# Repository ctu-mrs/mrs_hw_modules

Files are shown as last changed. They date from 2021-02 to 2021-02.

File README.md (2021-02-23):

# MRS Modules
Modules for MRS drone distribution boards to add a specific funtionality the distribution boards do not provide.

These modules are equipped with 1x10 header with 2mm pitch providing the module with UART connection, 5V from USB and VBAT from battery.

## MRS Module Host
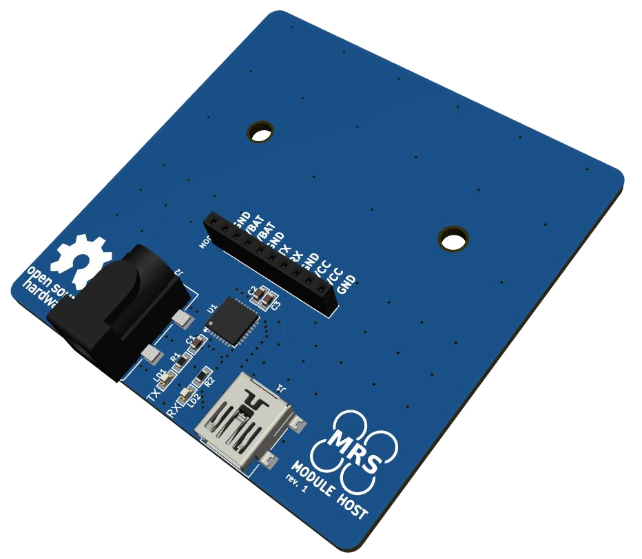
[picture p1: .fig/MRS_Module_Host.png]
mrs_module_host

This PCB serves as a host for MRS Modules for development. It's functionality is simple: provide power for VBAT pins (can be supplied using the 5.5/2.5mm barrel connector), power for the module's MCU and serial communication between the user's computer and the module's MCU (usinng the USB2.0B mini connector).

The VBAT input of the module is designed to be either 4S or 6S LiPo battery, but can be anything the designed module is capable of. Check the module's VBAT capabilities before plugging in any power source in case it is unsuitable and could damage the module.

## MRS Module Templates
Three templates are provided in case you aim to implement your own module: Small, Medium and Large.

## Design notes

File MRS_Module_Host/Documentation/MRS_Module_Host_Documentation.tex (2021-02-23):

\documentclass[12pt, a4paper]{article}

\usepackage[export]{adjustbox}
\usepackage{fancyhdr}
\usepackage[utf8]{inputenc}
\usepackage[english]{babel}
\usepackage{longtable}
\usepackage[margin=2cm, bottom=4cm]{geometry}
\usepackage{color,soul}
\usepackage{booktabs}
\usepackage{pdfpages}

\pagestyle{fancy}
\fancyhf{}% Clear all headers/footers
\renewcommand{\headrulewidth}{.4pt}% Header rule width
\renewcommand{\footrulewidth}{0pt}% No footer rule
\fancyhead[L]{% Left header
  \rule[-1\baselineskip]{0pt}{0pt}% Strut to ensure a 1/4 \baselineskip between image and header rule
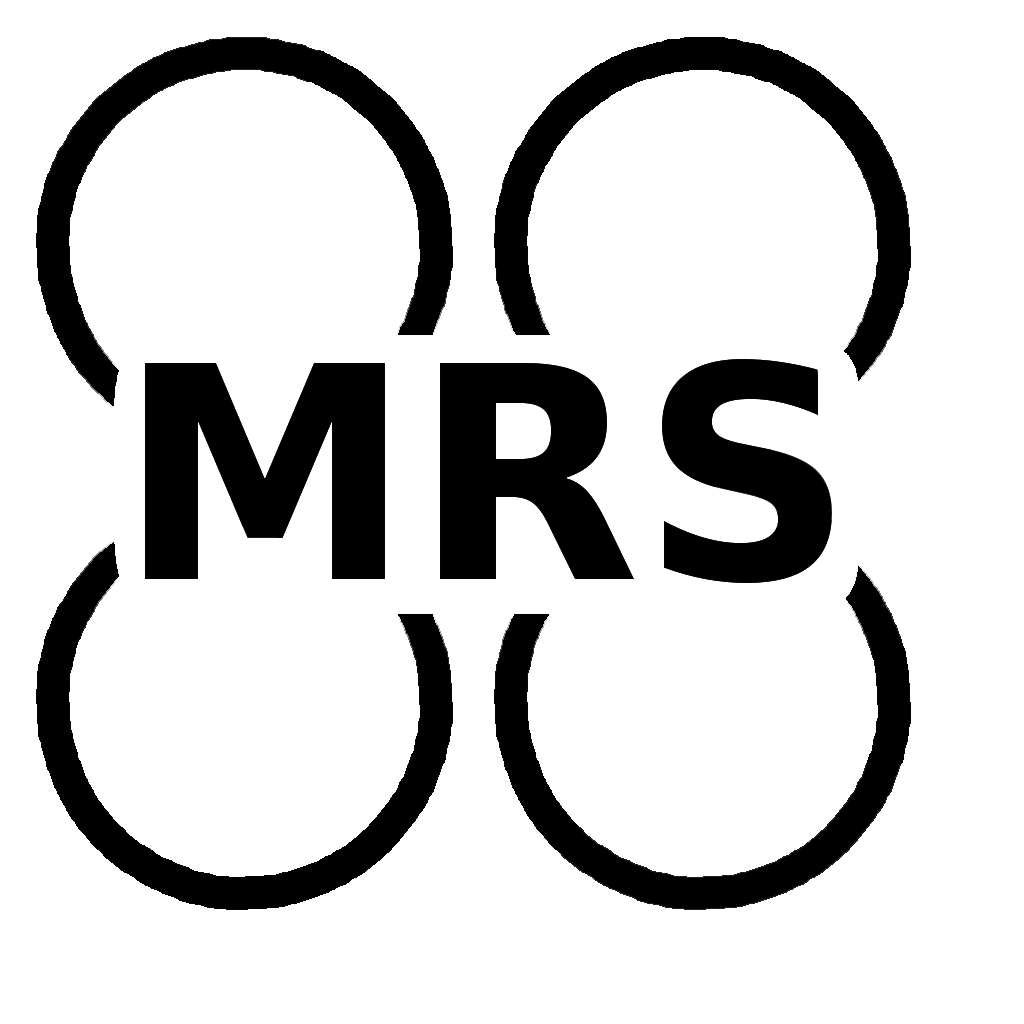
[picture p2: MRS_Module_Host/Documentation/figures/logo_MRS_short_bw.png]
  % Image
  \quad% Space
}

\fancyhead[R]{
MRS MODULE HOST
}

\chead{\thepage}

\title{
\Huge{MRS MODULE HOST}\\
{REVISION 1}\\
\vspace{0.5cm}
\LARGE{David Zaitlik}\\
\vspace{0.5cm}
\normalsize{\textit{Multi-Robot Systems Group, FEE CTU in Prague}}\\
\vspace{1.5cm}
\vfill
\begin{figure}[h]
\centering
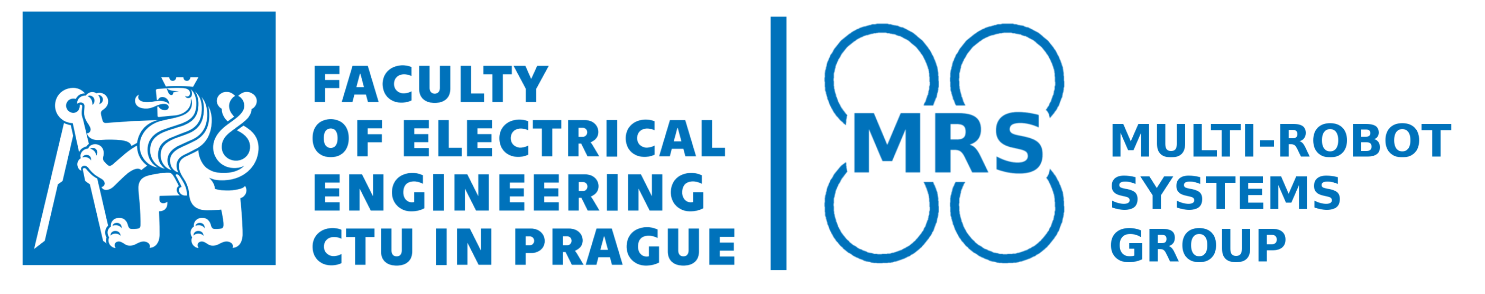
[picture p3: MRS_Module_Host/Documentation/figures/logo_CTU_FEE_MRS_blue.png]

\end{figure}
\date{\today}

}

\setlength{\headheight}{3.5\baselineskip}% To accommodate new oversized header

\begin{document}
\clearpage
\maketitle
\thispagestyle{empty}

\pagebreak
\tableofcontents
\listoffigures
\listoftables
\thispagestyle{empty}

\pagebreak
\setcounter{page}{1}
\pagenumbering{arabic}
\section{Introduction}
MRS Modules are designed to be powered by a drone power supply and to communicate with an Intel NUC onboard computer. However, it is inconvenient to have it plugged into a drone for development and testing. Therefore this Host Board was designed.\\
\\
This board contains a single UART to USB converter to provide communication between the module's MCU and the developer's laptop.\\
\\
The 5V is supplied directly from USB, and the "battery voltage" can be provided using the barrel connector and an external power supply.

\begin{figure}[h]
\centering
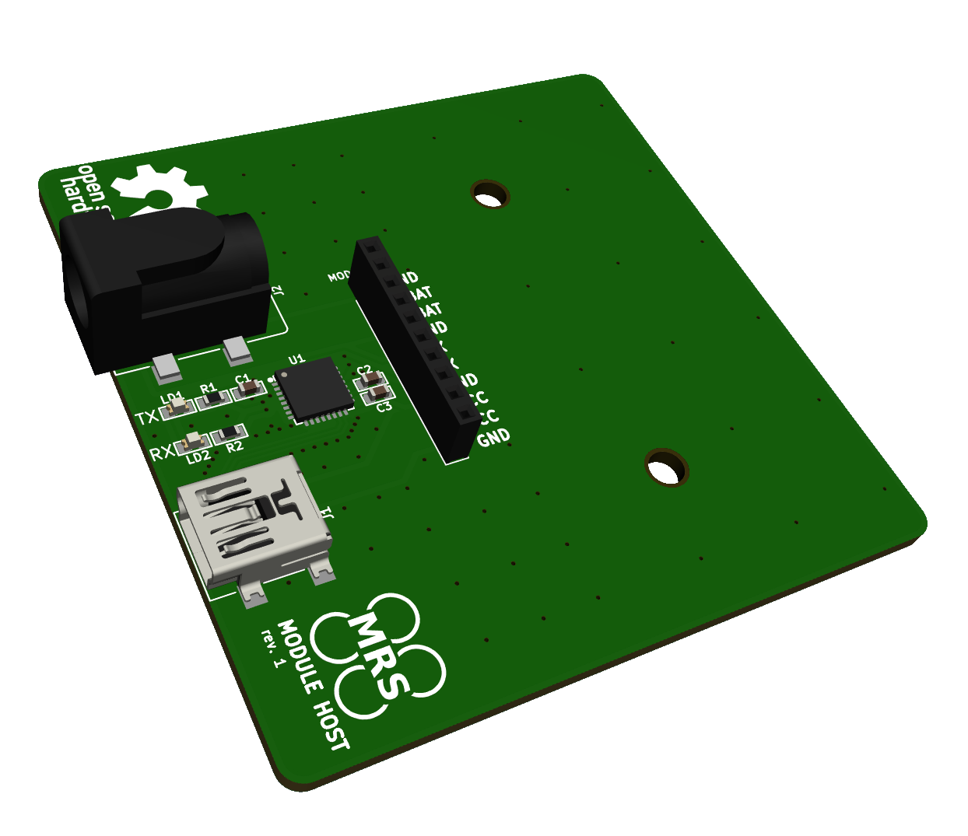
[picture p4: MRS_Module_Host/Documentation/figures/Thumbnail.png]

\caption{MRS MODULE HOST: Thumbnail}
\label{fig:thumbnail}
\end{figure}

\pagebreak
\section{Dimensions}
The board is 60mm wide and 60mm long with mounting holes for an MRS module.

The mechanical drawing can be seen in Figure \ref{fig:dimensions} below.

\begin{figure}[h]
\centering

\caption{MRS MODULE HOST: Dimensions}
\label{fig:dimensions}
\end{figure}

\pagebreak
\section{Connectors}
The Module Host Board has connectors only on the top layer.
The connector marked as \verb|USB B MINI| is a standard USB B Mini connector. It provides connectivity between the user's computer and an MRS Module's MCU using an FTDI IC and 5V for the module.\\
\\
The connector marked as \verb|POWER (VBAT)| provides power for the rest of the module (if needed). This power source should be in a similar voltage range as a 4S or 6S battery used on drones.\\
\\
The connector marked as \verb|MRS MODULE| is a standard connector for MRS Modules, and its pinout is as follows:

\begin{center}
\begin{tabular}{|l|l|}
\hline
\multicolumn{2}{|p{3cm}|}{\centering\textbf{MRS MODULE}} \\ \hline
1               & GND         			\\ \hline
2               & VBAT        			\\ \hline
3               & VBAT        			\\ \hline
4               & GND         			\\ \hline
5               & UART\verb|_|TX    	\\ \hline
6               & UART\verb|_|RX     	\\ \hline
7               & GND         			\\ \hline
8               & 5V          			\\ \hline
9               & 5V          			\\ \hline
10              & GND         			\\ \hline
\end{tabular}
\end{center}

\subsection{Connector Placement Drawing}
\begin{figure}[h]
\centering

\caption{MRS MODULE HOST: Connectors Placement, Top Layer}
\label{fig:connectors_top}
\end{figure}

\pagebreak
\newgeometry{left=1cm,right=1cm}
\section{Bill Of Materials and Assembly Drawings}
\begin{longtable}{|p{0.5cm}|p{5cm}|p{5cm}|p{5cm}|p{1.7cm}|}
\hline
\textbf{\#} & \textbf{References}                                                          & \textbf{Value} & \textbf{Footprint} & \textbf{Quantity} 		\\ \hline
1 & C1       & 10uF               & 0603 & 1      				\\ \hline
2 & C2, C3   & 0.1uF              & 0603 & 2                	\\ \hline
3 & J1       & USB2.0B\_mini      & USB\_Mini-B   & 1       	\\ \hline
4 & J2       & Barrel\_Jack       & ADC-028-2-TR   & 1      	\\ \hline
5 & LD1, LD2 & D\_LED\_0603\_BLUE & 0603 & 2                	\\ \hline
6 & MODULE1  & MRS\_Module        & Header 1x10 2mm pitch & 1 	\\ \hline
7 & R1, R2   & 1k                 & R0603 & 2                  	\\ \hline
8 & U1       & FT232RQ            & QFN\_32-5x5mm & 1     	  	\\ \hline
\caption{MRS MODULE HOST: Bill Of Materials}
\label{tab:bom}
\end{longtable}
\vfill
\restoregeometry

\pagebreak
% change scale and angle accordingly
\includepdf[pages=-, scale=1.25, angle=0, pagecommand={}]{figures/Assembly_top.pdf}

\pagebreak
\section{Schematic}


\end{document}

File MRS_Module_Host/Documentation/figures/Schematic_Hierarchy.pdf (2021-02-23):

# MAIN SHEET

# Sheet 1

# USB, FTDI

# Sheet 2

USB_HUB_UP_VBUS
USB_HUB_UP_D-USB_HUB_UP_D+

FTDI_4232_A_RX
FTDI_4232_A_TX

FTDI_4232_B_RX
FTDI_4232_B_TX

FTDI_4232_C_RX
FTDI_4232_C_TX

FTDI_4232_D_RX
FTDI_4232_D_TX

USB_BF1_EN
USB_BF1_D-USB_BF1_D+

USB_BF2_EN
USB_BF2_D-USB_BF2_D+

USB_SPARE_EN
USB_SPARE_D-USB_SPARE_D+

# POWER SOURCES

# Sheet 3

3V3

5V

PIXHWAK_5V_1

PIXHWAK_5V_2

# PLACEHOLDER

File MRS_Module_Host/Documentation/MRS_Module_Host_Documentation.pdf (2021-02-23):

# MRS MODULE HOST REVISION 1

# David Zaitlik

Multi-Robot Systems Group, FEE CTU in Prague

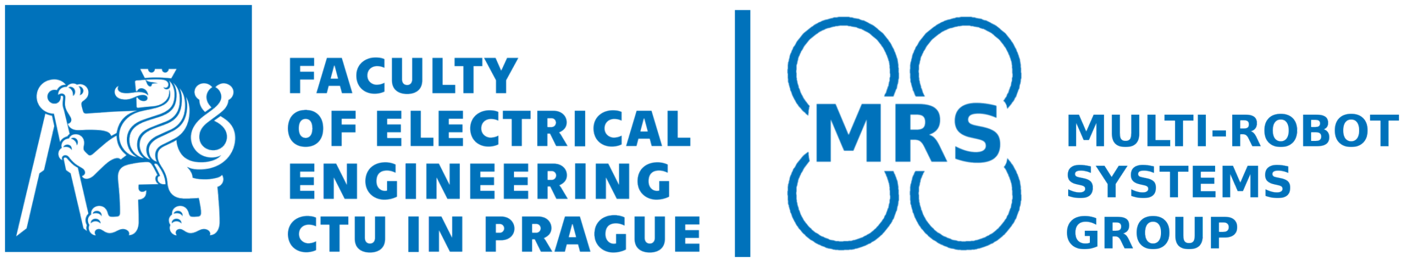
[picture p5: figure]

### December 15, 2020

## Contents

1 Introduction | 1
2 Dimensions | 2
3 Connectors | 3
3.1 Connector Placement Drawing | | 3
4 Bill Of Materials and Assembly Drawings | 4
5 Schematic | 6

## List of Figures

1 | MRS MODULE HOST: Thumbnail | | 1
2 | MRS MODULE HOST: Dimensions | | 2
3 | MRS MODULE HOST: Connectors Placement, Top Layer | | 3

## List of Tables

1 | MRS MODULE HOST: Bill Of Materials | | 4

1 | MRS MODULE HOST

## 1 Introduction

MRS Modules are designed to be powered by a drone power supply and to communicate with an Intel NUC onboard computer. However, it is inconvenient to have it plugged into a drone for development and testing. Therefore this Host Board was designed.

This board contains a single UART to USB converter to provide communication between the module’s MCU and the developer’s laptop.

The 5V is supplied directly from USB, and the ”battery voltage” can be provided using the barrel connector and an external power supply.

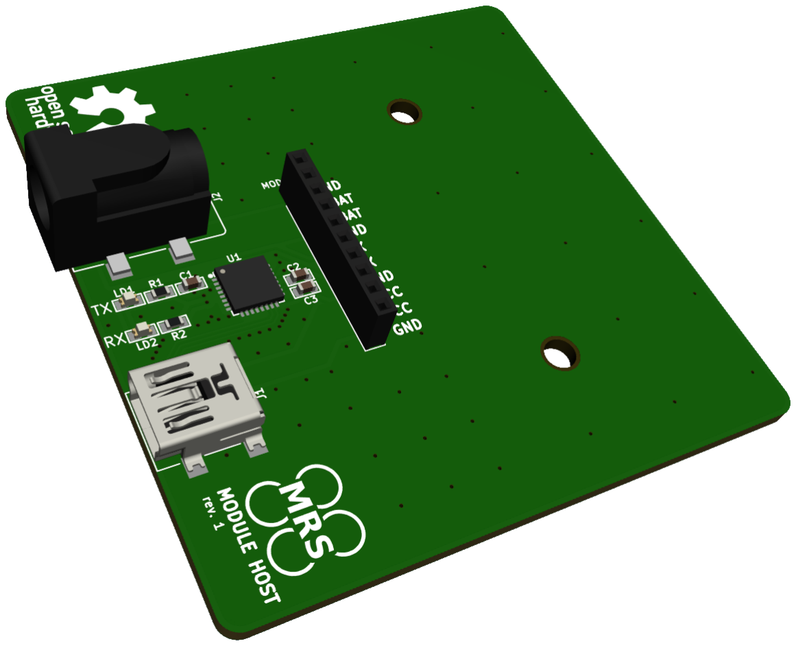
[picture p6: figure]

Figure 1: MRS MODULE HOST: Thumbnail

## 2 Dimensions

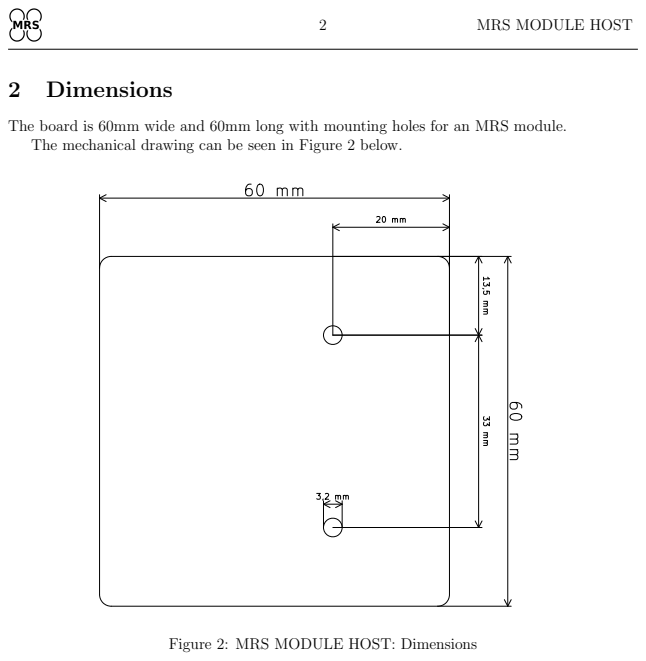
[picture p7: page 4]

The board is 60mm wide and 60mm long with mounting holes for an MRS module.
The mechanical drawing can be seen in Figure 2 below.

Figure 2: MRS MODULE HOST: Dimensions

## 3 Connectors

The Module Host Board has connectors only on the top layer. The connector marked as USB B MINI is a standard USB B Mini connector. It provides connectivity between the user’s computer and an MRS Module’s MCU using an FTDI IC and 5V for the module.

The connector marked as POWER (VBAT) provides power for the rest of the module (if needed). This power source should be in a similar voltage range as a 4S or 6S battery used on drones.

The connector marked as MRS MODULE is a standard connector for MRS Modules, and its pinout is as follows:

MRS
MODULE
1 | GND
2 | VBAT
3 | VBAT
4 | GND
5 | UART_TX
6 | UART_RX
7 | GND
8 | 5V
9 | 5V
10 | GND

### 3.1 Connector Placement Drawing

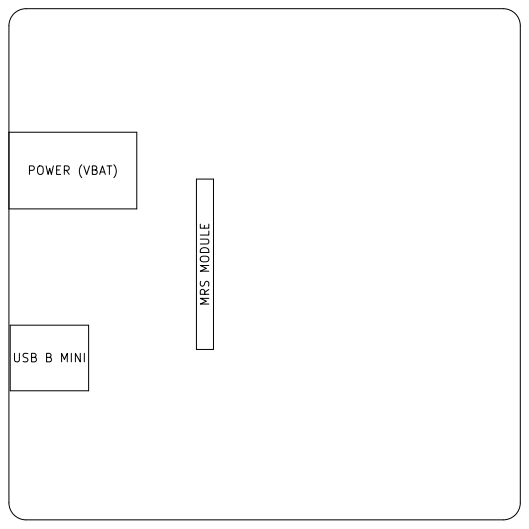
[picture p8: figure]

Figure 3: MRS MODULE HOST: Connectors Placement, Top Layer

## 4 Bill Of Materials and Assembly Drawings

# | References | Value | Footprint | Quantity

1 | C1 | 10uF | 0603 | 1
2 | C2, C3 | 0.1uF | 0603 | 2
3 | J1 | USB2.0B mini | USB Mini-B | 1
4 | J2 | Barrel Jack | ADC-028-2-TR | 1
5 | LD1, LD2 | D LED 0603 BLUE | 0603 | 2
6 | MODULE1 | MRS Module | Header 1x10 2mm pitch | 1
7 | R1, R2 | 1k | R0603 | 2
8 | U1 | FT232RQ | QFN 32-5x5mm | 1
Table 1: MRS MODULE HOST: Bill Of Materials

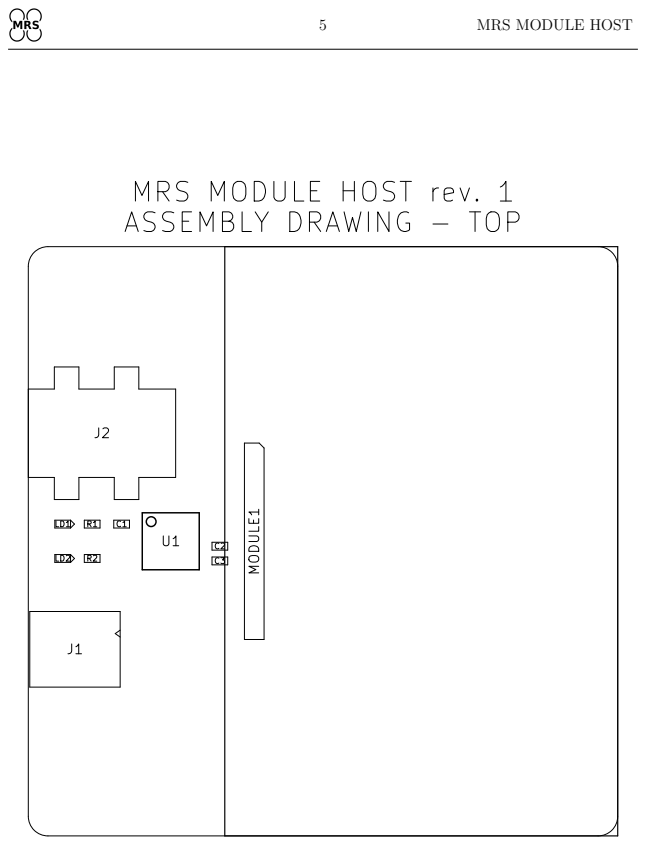
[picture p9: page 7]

## 5 Schematic

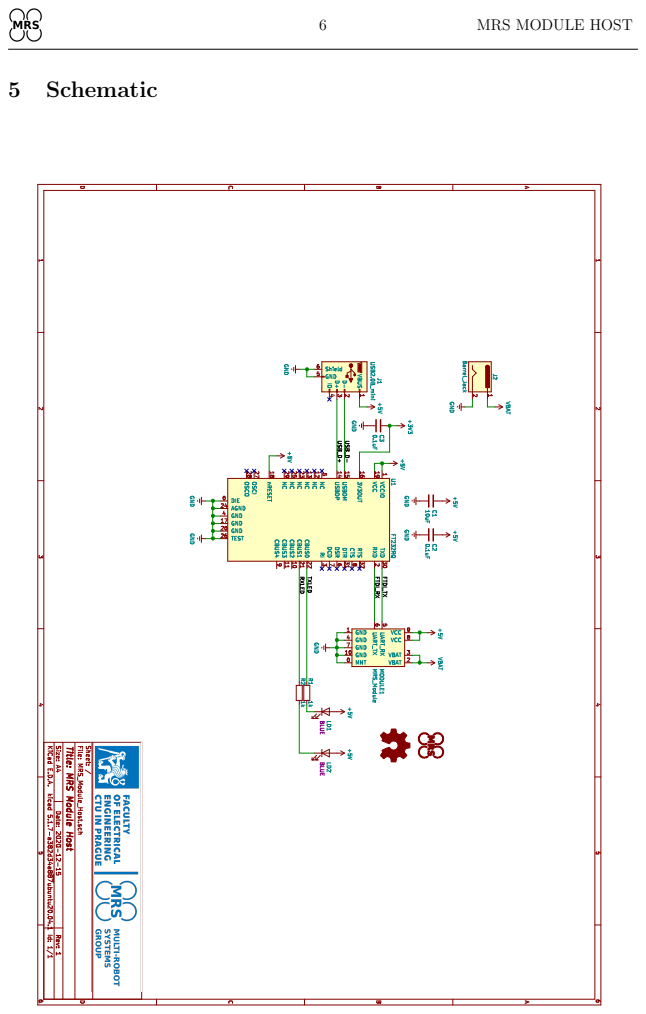
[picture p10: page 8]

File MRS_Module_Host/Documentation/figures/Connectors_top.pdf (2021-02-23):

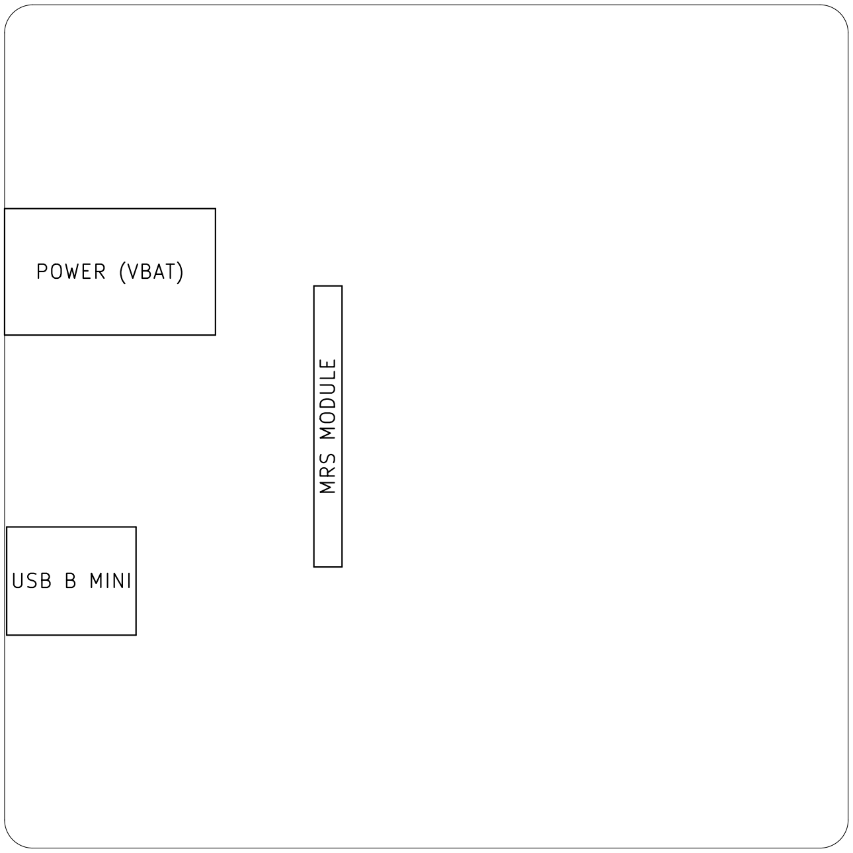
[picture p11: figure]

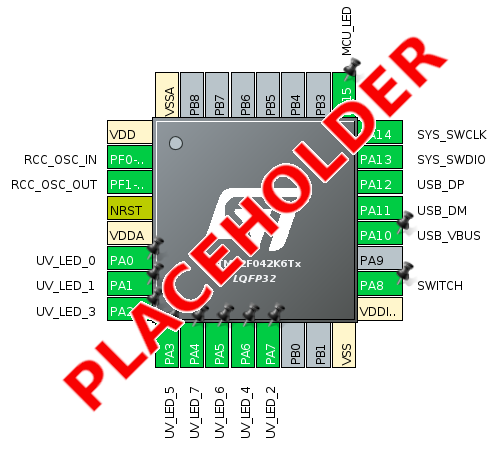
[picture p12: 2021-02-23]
MRS_Module_Host/Documentation/figures/MCU_Pinout.png

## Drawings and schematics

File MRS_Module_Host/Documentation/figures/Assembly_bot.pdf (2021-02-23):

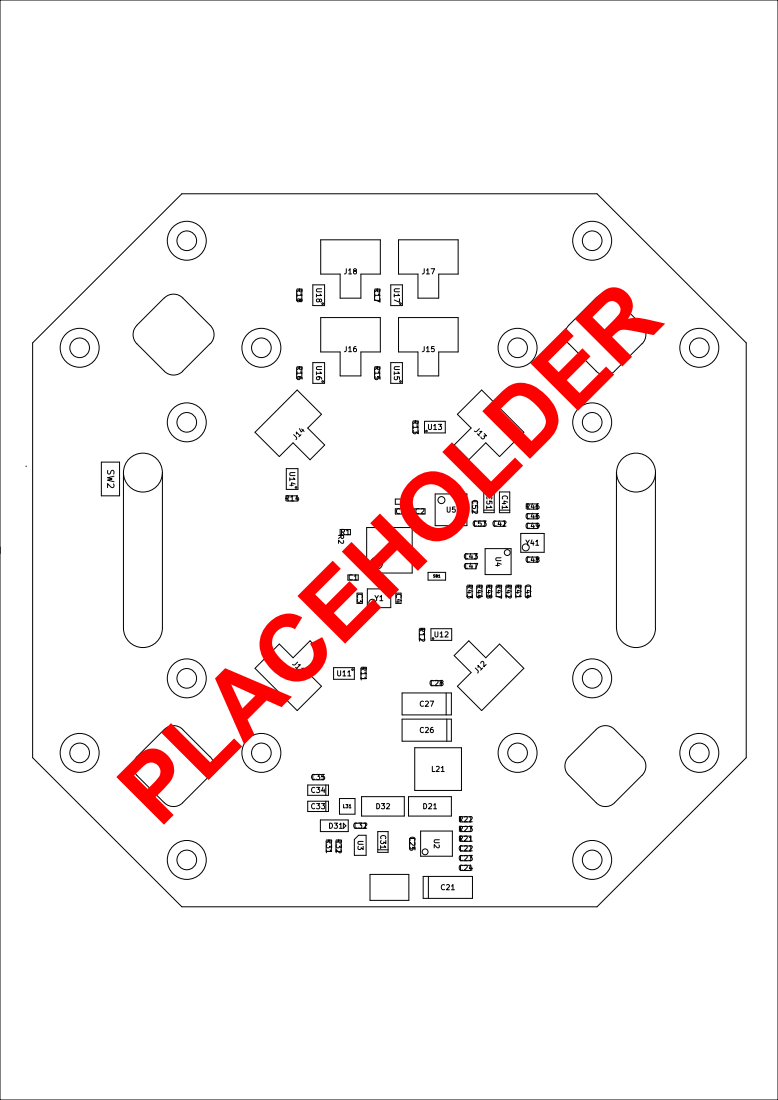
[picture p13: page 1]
PLACEHOLDER

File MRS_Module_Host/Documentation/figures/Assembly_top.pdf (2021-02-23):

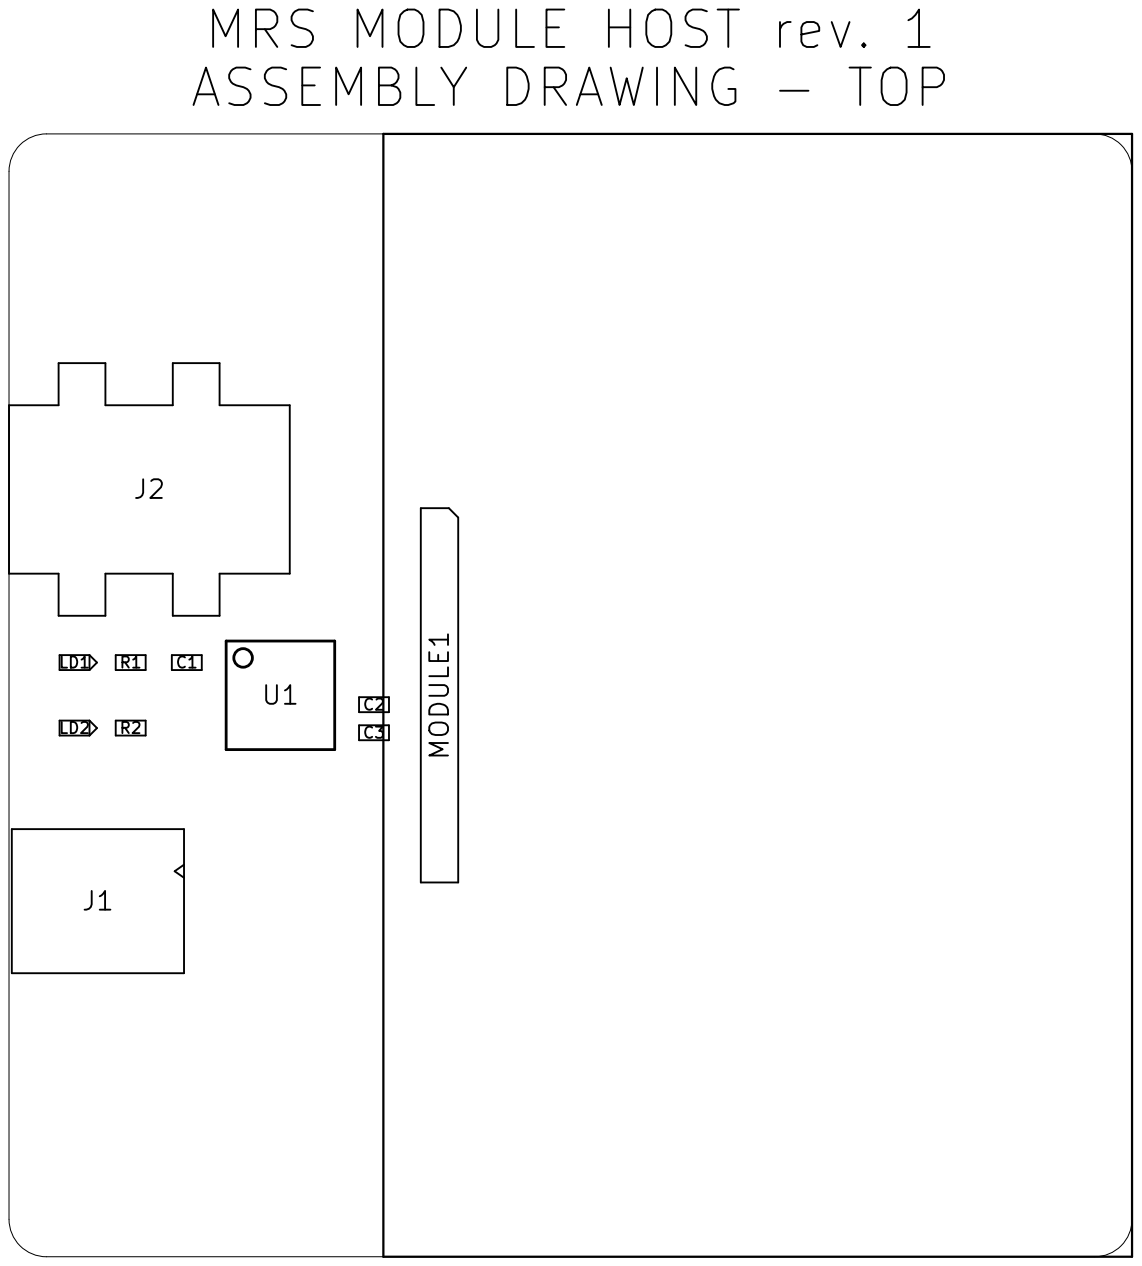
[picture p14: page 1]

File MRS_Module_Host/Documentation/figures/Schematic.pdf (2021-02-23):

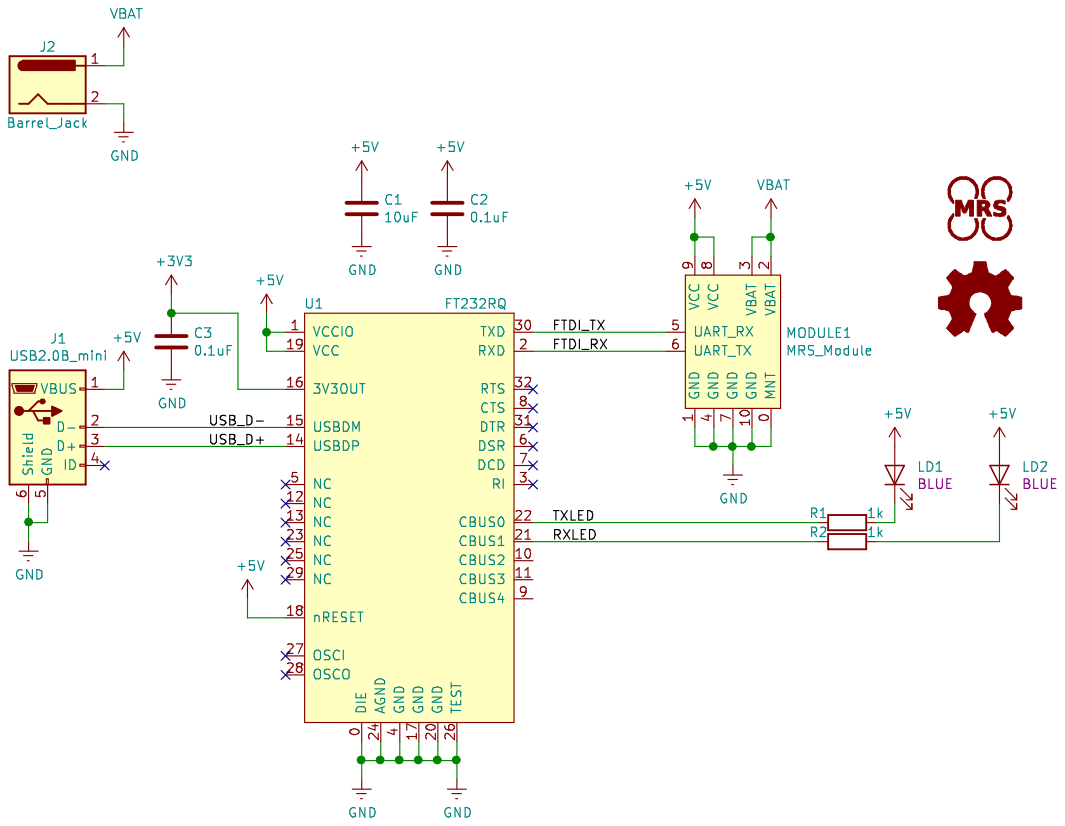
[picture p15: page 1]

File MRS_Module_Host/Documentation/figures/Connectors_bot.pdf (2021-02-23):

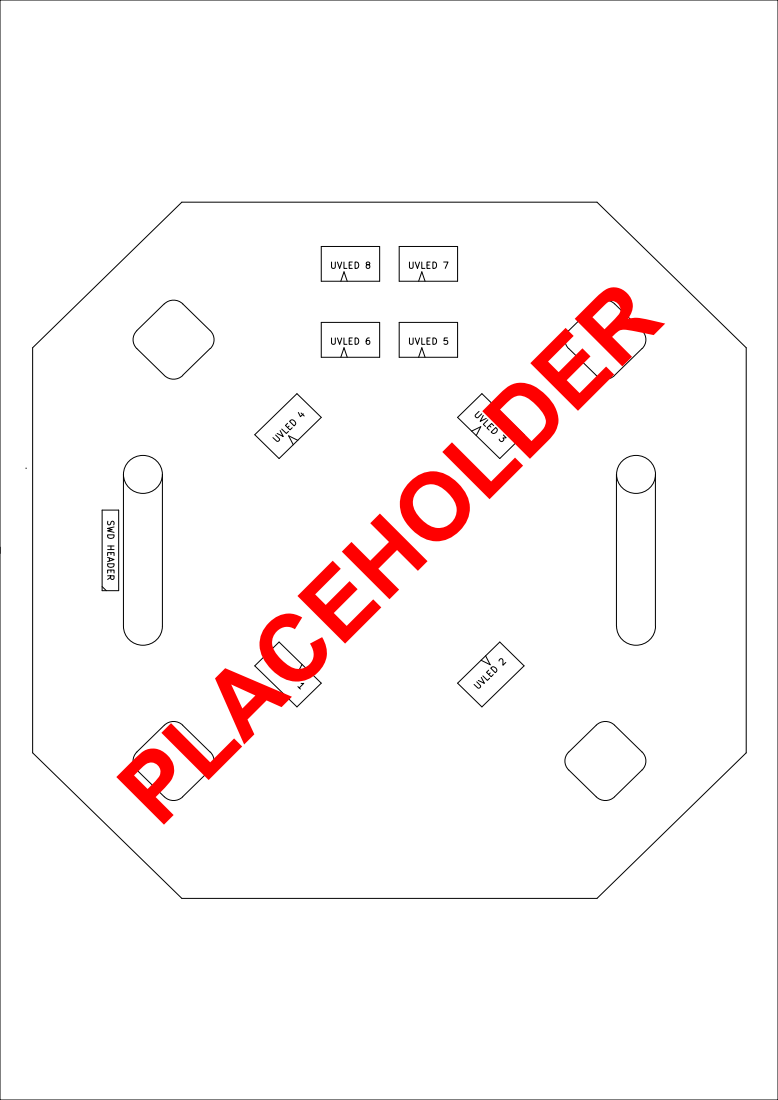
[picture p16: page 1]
PLACEHOLDER

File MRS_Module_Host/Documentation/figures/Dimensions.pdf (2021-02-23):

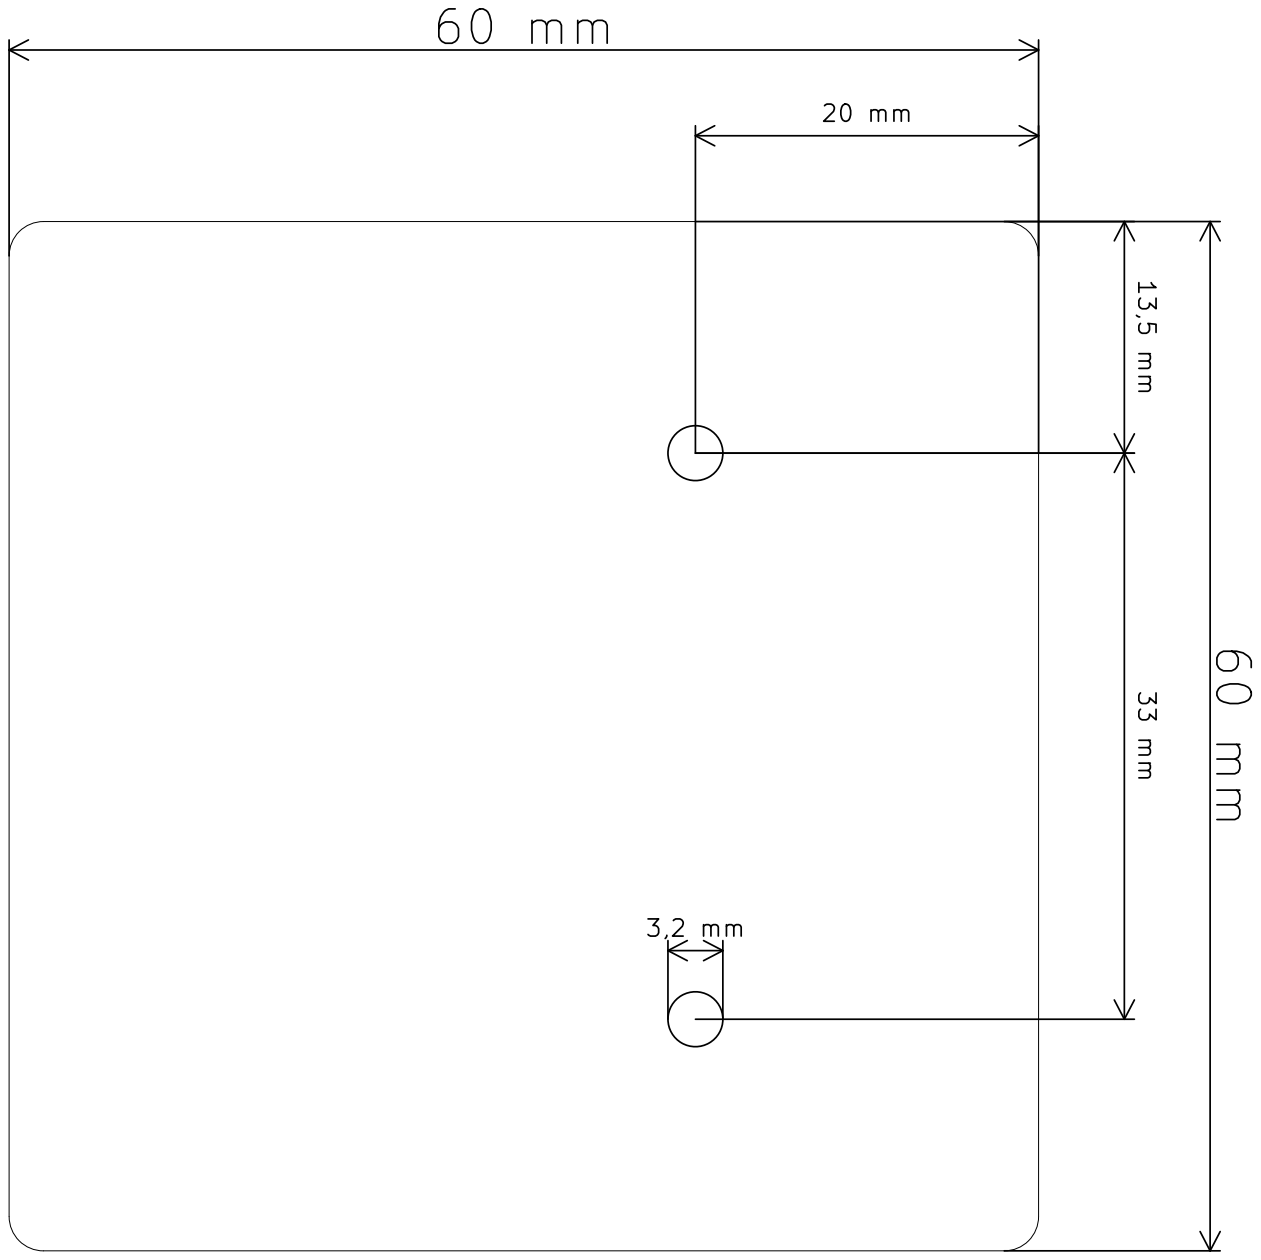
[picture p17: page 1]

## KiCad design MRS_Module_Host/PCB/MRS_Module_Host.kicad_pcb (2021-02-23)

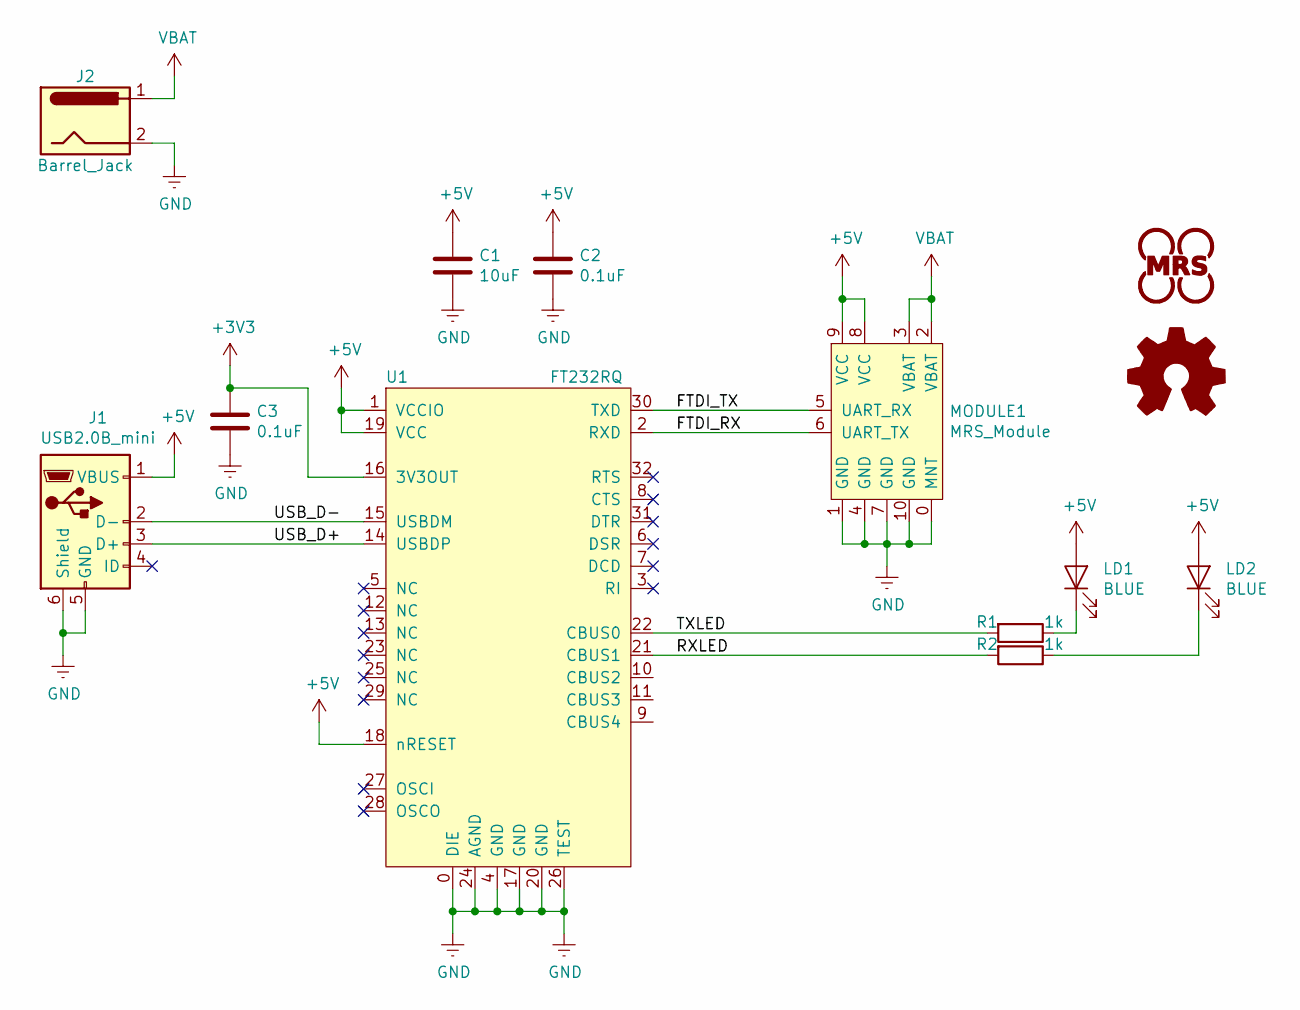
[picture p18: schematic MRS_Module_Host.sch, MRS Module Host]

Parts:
C1: 10uF; C0603; Farnell 2456110
C2, C3: 0.1uF; C0603; Farnell 2821272
J1: USB2.0B_mini; USB_Mini-B_Lumberg_2486_01_Horizontal
J2: Barrel_Jack; ADC-028-2-TR; Digikey 2073-DCJ200-05-A-K1-ACT-ND
LD1, LD2: D_LED_0603_BLUE; LED_0603; Farnell *
LOGO1: MRS_Logo; MRS_10mm
LOGO2: Logo_Open_Hardware_Small; OSHW-Logo_11.4x12mm_SilkScreen
MODULE1: MRS_Module; MRS_MODULE_MEDIUM
R1, R2: 1k; R0603; Farnell 2861864
U1: FT232RQ; QFN_32-5x5mm; Farnell 1146033

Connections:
+3V3: C3.1, U1.16 (3V3OUT)
+5V: C1.1, C2.1, J1.1 (VBUS), LD1.2 (A), LD2.2 (A), MODULE1.8 (VCC), MODULE1.9 (VCC), U1.1 (VCCIO), U1.18 (nRESET), U1.19 (VCC)
/FTDI_RX: MODULE1.6 (UART_TX), U1.2 (RXD)
/FTDI_TX: MODULE1.5 (UART_RX), U1.30 (TXD)
/RXLED: R2.2, U1.21 (CBUS1)
/TXLED: R1.2, U1.22 (CBUS0)
/USB_D+: J1.3 (D+), U1.14 (USBDP)
/USB_D-: J1.2 (D-), U1.15 (USBDM)
GND: C1.2, C2.2, C3.2, J1.5 (GND), J1.6 (Shield), J2.2, MODULE1.0 (MNT), MODULE1.1 (GND), MODULE1.4 (GND), MODULE1.7 (GND), MODULE1.10 (GND), U1.0 (DIE), U1.4 (GND), U1.17 (GND), U1.20 (GND), U1.24 (AGND), U1.26 (TEST)
unnamed: LD1.1 (K), R1.1
unnamed: LD2.1 (K), R2.1
VBAT: J2.1, MODULE1.2 (VBAT), MODULE1.3 (VBAT)

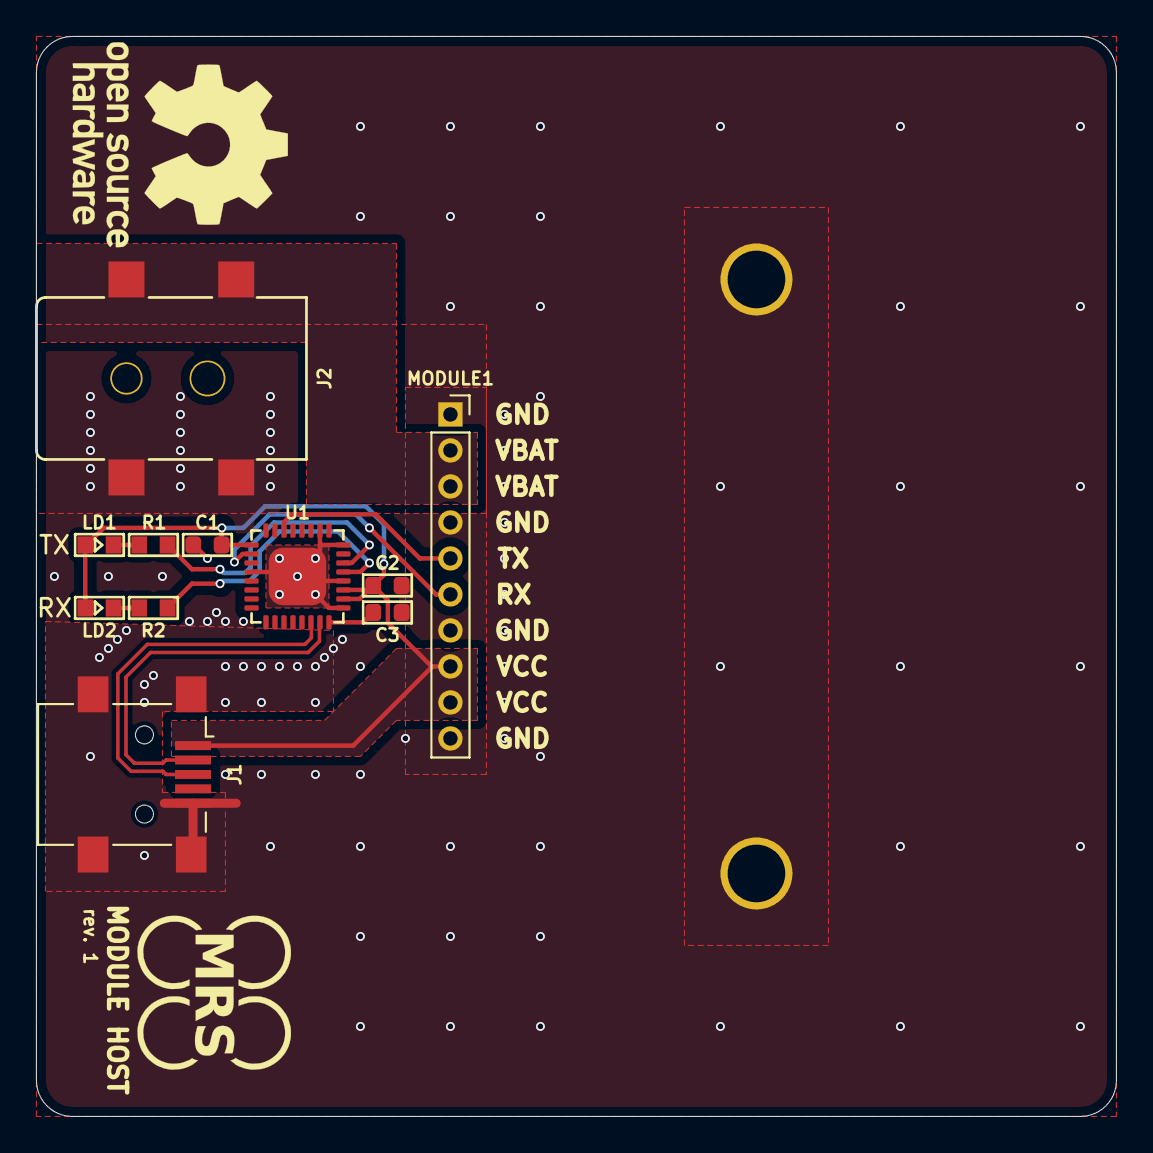
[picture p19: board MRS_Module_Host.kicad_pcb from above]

Board: 2 copper layers, 60.0 x 60.0 mm, 13 parts (0 on the bottom side), 12 nets.

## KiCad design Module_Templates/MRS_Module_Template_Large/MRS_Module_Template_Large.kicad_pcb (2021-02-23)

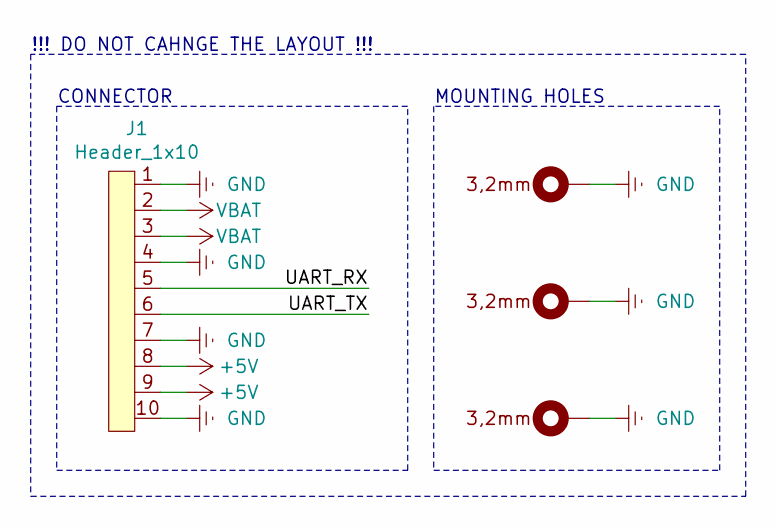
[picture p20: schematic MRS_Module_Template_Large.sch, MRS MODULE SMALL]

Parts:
H1, H2, H3: Mounting_hole_plated_3,2mm; Mounting_hole_plated_3,2mm_thin
J1: Header_1x10; PinHeader_1x10_P2.00mm_Vertical

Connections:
+5V: J1.8, J1.9
/UART_RX: J1.5
/UART_TX: J1.6
GND: H1.1, H2.1, H3.1, J1.1, J1.4, J1.7, J1.10
VBAT: J1.2, J1.3

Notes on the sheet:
CONNECTOR
MOUNTING HOLES
!!! DO NOT CAHNGE THE LAYOUT !!!

Board: 2 copper layers, 4 parts (1 on the bottom side), 3 nets, no tracks yet.

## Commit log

2021-02-09 Added UVDAR Module PCB and Firmware.
2021-02-23 Added a basic template for custom modules.
    [MRS_Module_Template_Large.kicad_pcb, MRS_Module_Template_Large.sch, MRS_Module_Template_Medium.kicad_pcb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]
2021-02-23 Added MRS Host module.
    [MRS_Module_Host-B_Cu.gbr, MRS_Module_Host-B_Mask.gbr, MRS_Module_Host-B_Paste.gbr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]
